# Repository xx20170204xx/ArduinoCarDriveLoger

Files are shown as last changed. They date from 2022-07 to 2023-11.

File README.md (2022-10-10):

# ArduinoCarDriveLoger
<!-- https://github.com/xx20170204xx/ArduinoCarDriveLoger -->

## description
Android+Arduino+Unityを使ってのマルチメーターを目指したものです。
※水温・油温・油圧計を表示できるようにしたもの

<!--
## Test
![TextMessage](UnityClient/MyMultiMeter/Assets/Image/icons.png)
-->

## Figure
### Android Client
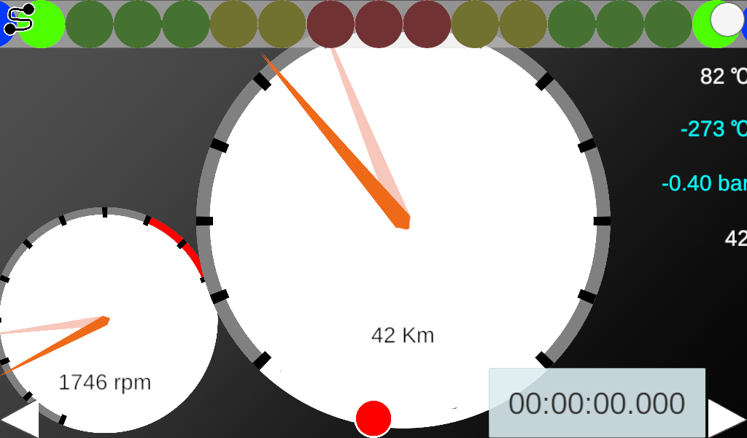
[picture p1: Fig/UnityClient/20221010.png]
Figure1. Client

### Device(Arduino Nano)
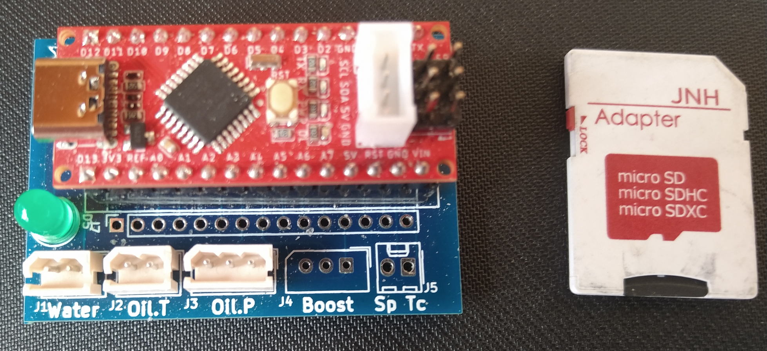
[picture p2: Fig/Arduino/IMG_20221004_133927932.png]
Figure2. Arduino Nano

### schematic
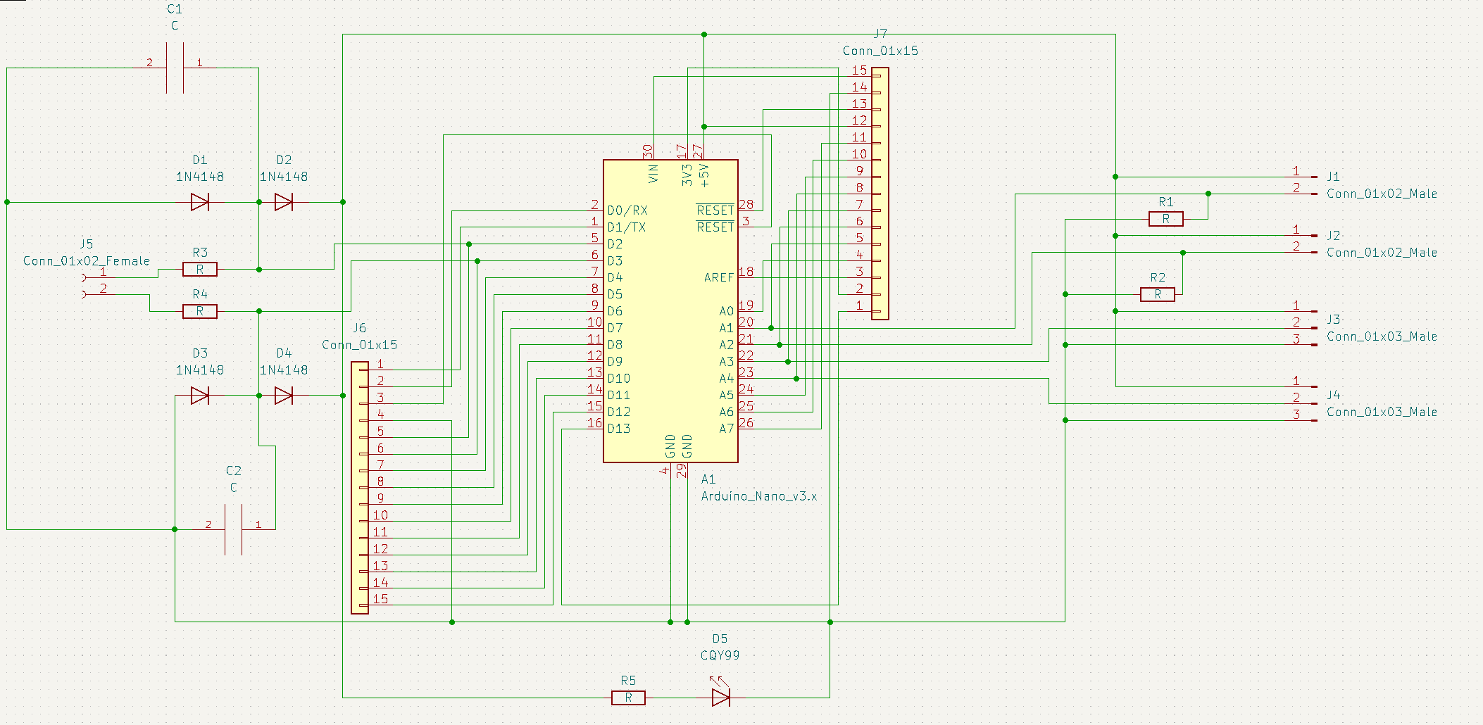
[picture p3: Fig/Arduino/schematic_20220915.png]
Figure3. Arduino Nano


2022/10/04
<!-- https://docs.github.com/ja/get-started/writing-on-github/getting-started-with-writing-and-formatting-on-github/basic-writing-and-formatting-syntax -->
<!-- EOF -->

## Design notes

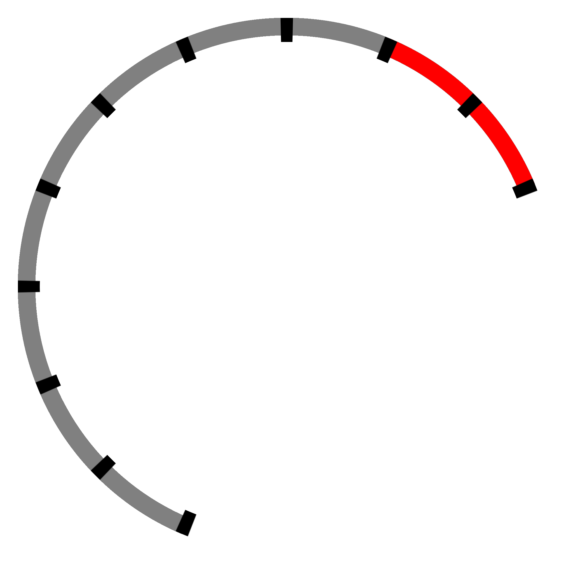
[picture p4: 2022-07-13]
UnityClient/MyMultiMeter/Assets/Image/TachoMeter.png

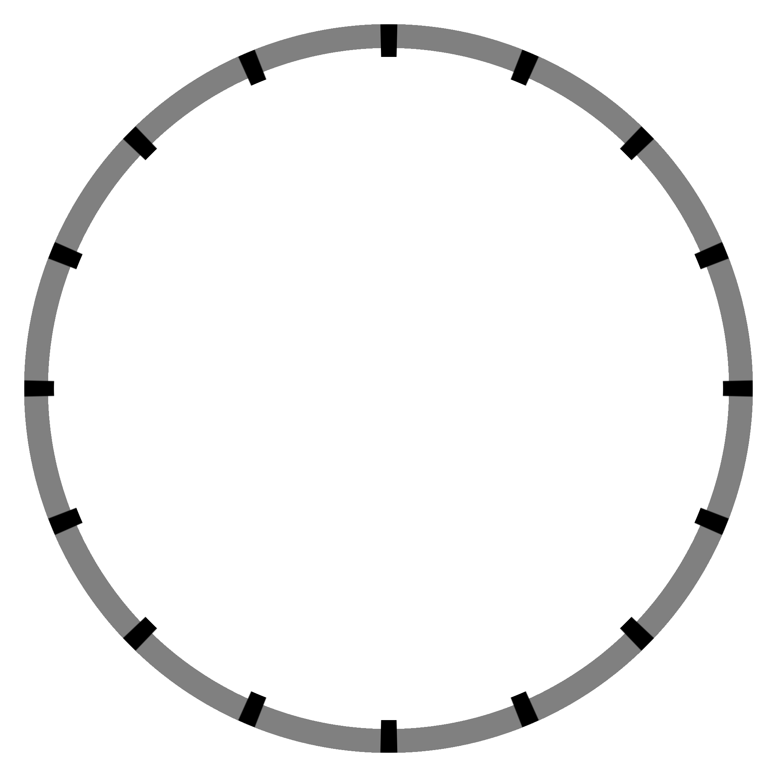
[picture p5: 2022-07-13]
UnityClient/MyMultiMeter/Assets/Image/MeterBase.png

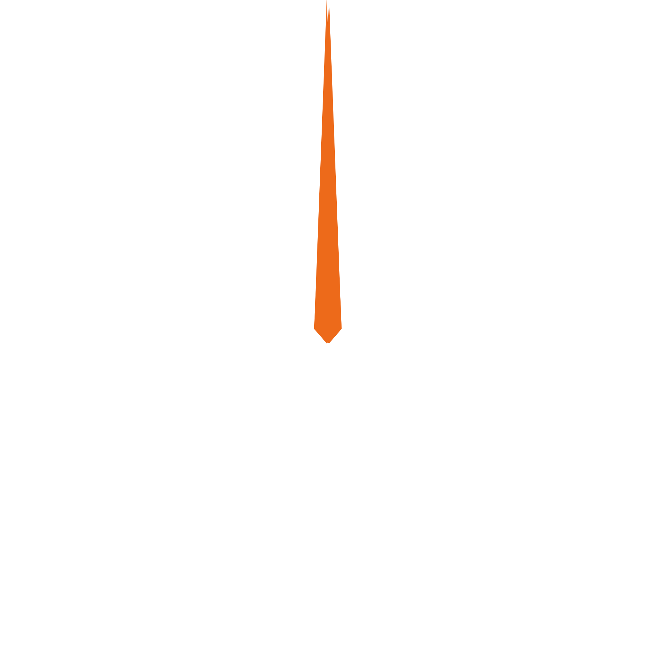
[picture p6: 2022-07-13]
UnityClient/MyMultiMeter/Assets/Image/MeterNeedle.png

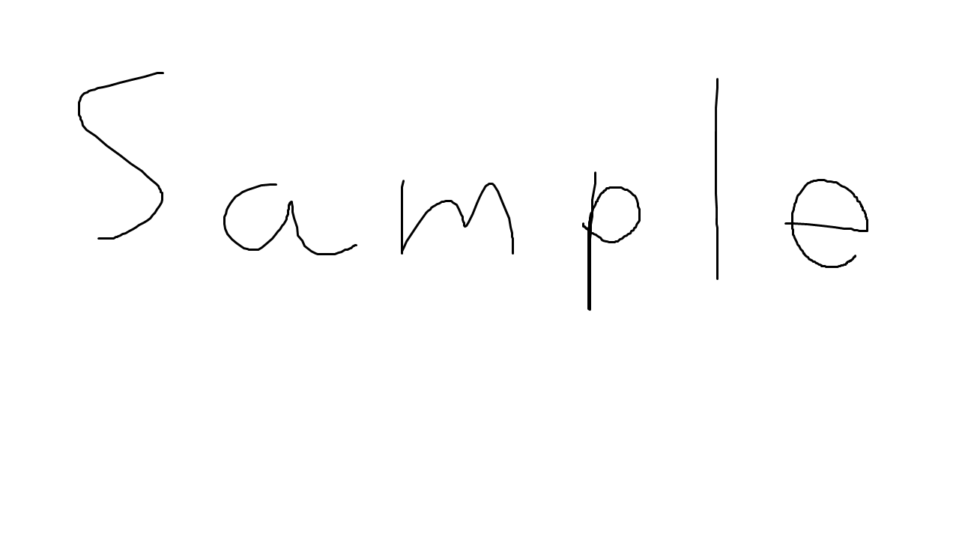
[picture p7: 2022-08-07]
UnityClient/MyMultiMeter/Assets/bundle/ModSample1/Thumbnail_Image.png

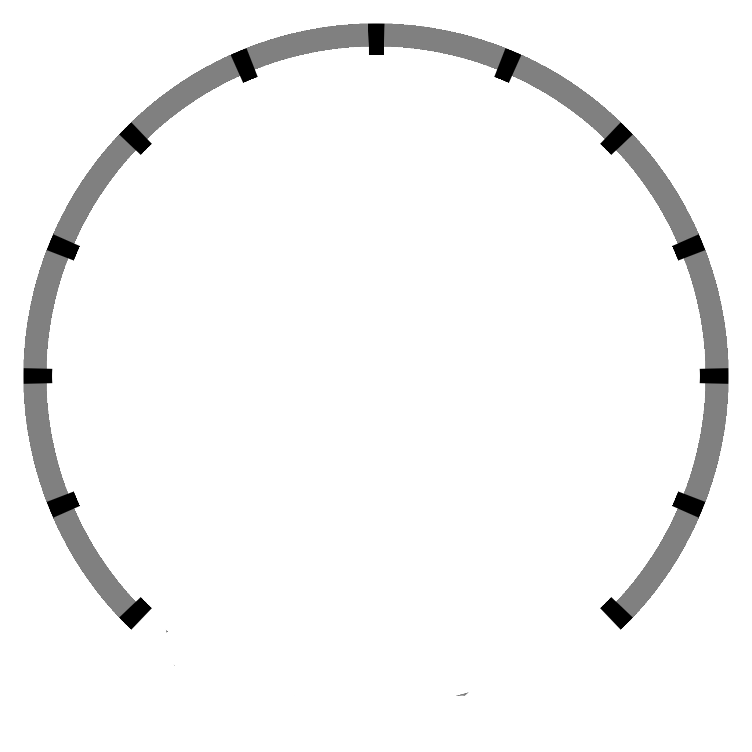
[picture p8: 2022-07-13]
UnityClient/MyMultiMeter/Assets/Image/SpeedMeter.png

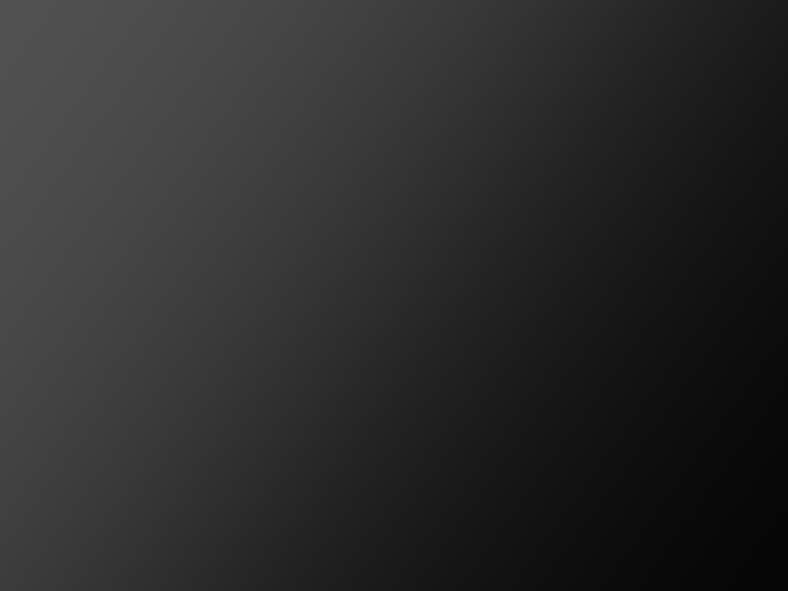
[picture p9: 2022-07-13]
UnityClient/MyMultiMeter/Assets/Image/background.png

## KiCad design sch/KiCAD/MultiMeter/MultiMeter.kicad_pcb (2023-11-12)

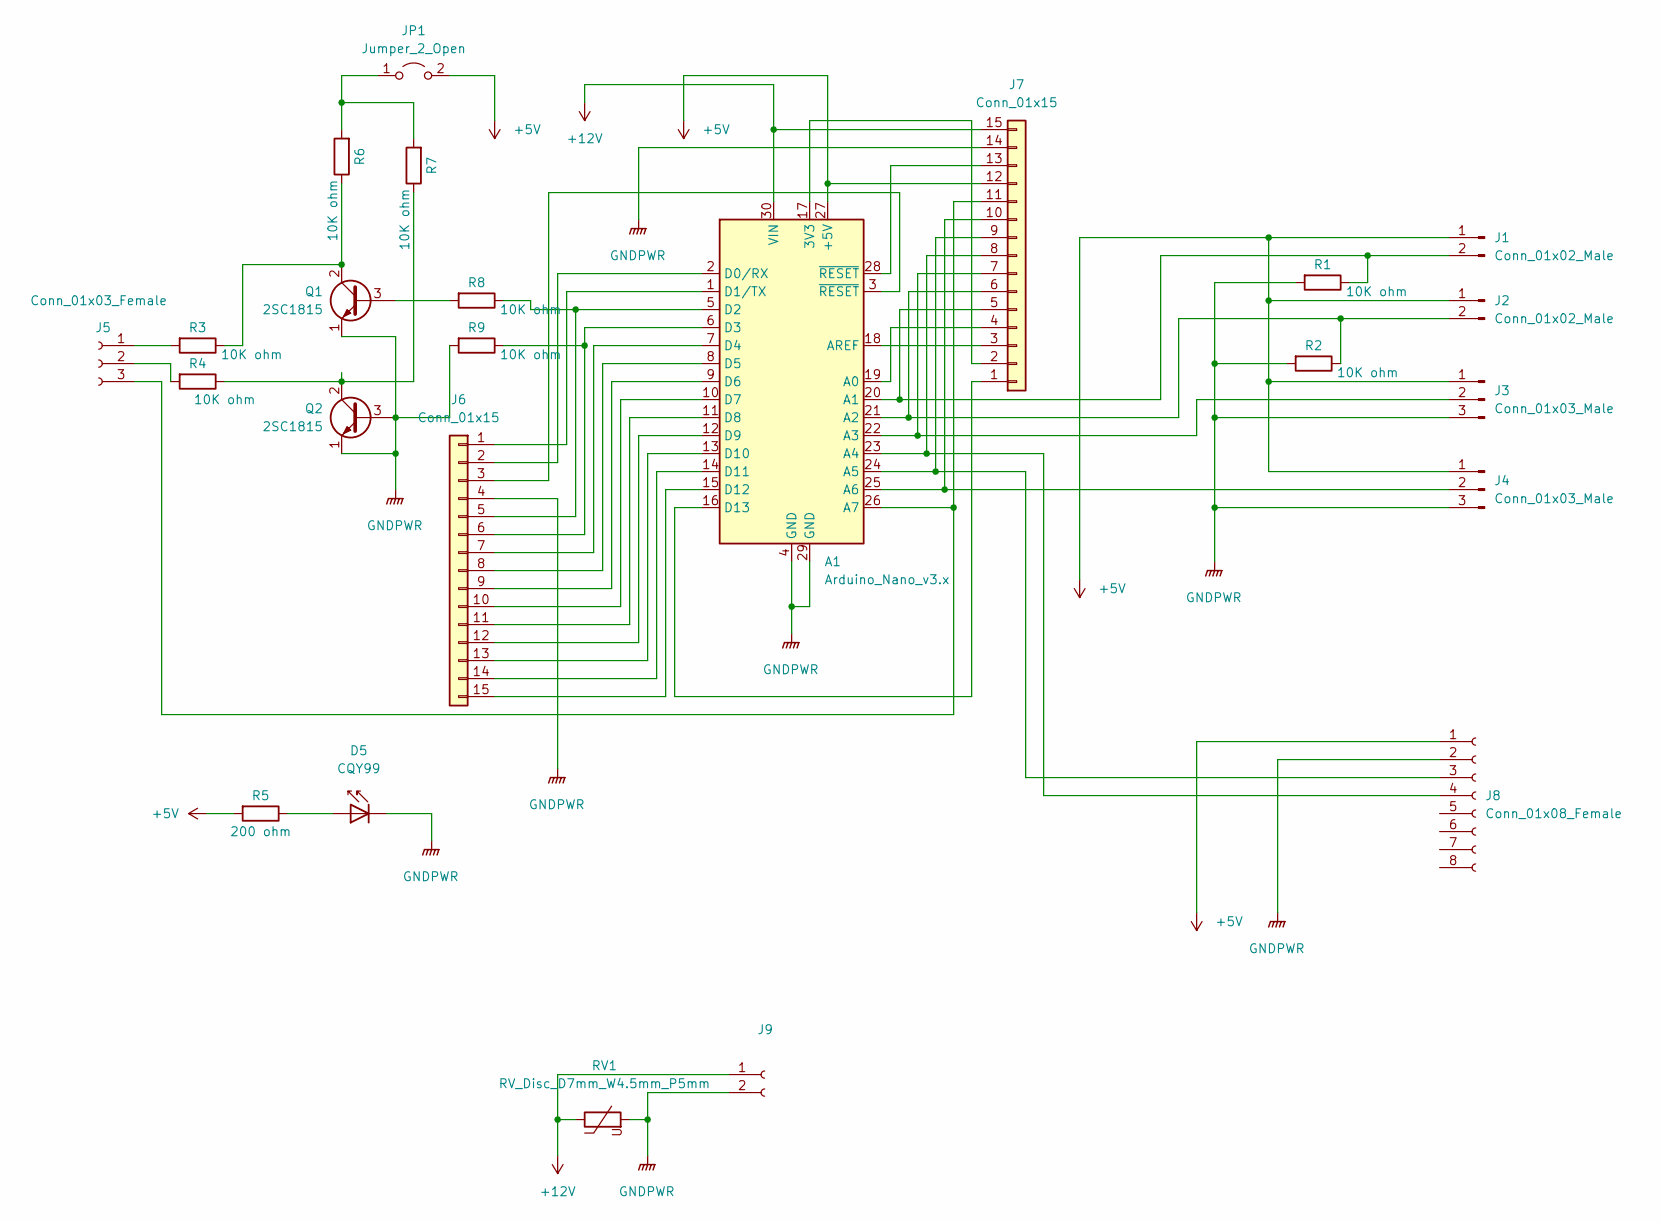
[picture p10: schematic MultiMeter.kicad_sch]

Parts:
A1: Arduino_Nano_v3.x; Arduino_Nano
D5: CQY99; LED_D5.0mm_IRGrey
J1, J2: Conn_01x02_Male; Molex_SPOX_5268-02A_1x02_P2.50mm_Horizontal
J3, J4: Conn_01x03_Male; Molex_SPOX_5268-03A_1x03_P2.50mm_Horizontal
J5: Conn_01x03_Female; Molex_KK-254_AE-6410-03A_1x03_P2.54mm_Vertical
J6, J7: Conn_01x15; PinSocket_1x15_P2.54mm_Vertical
J8: Conn_01x08_Female; JST_XH_B8B-XH-A_1x08_P2.50mm_Vertical
J9: (no value)
JP1: Jumper_2_Open; PinHeader_1x02_P2.54mm_Vertical
Q1, Q2: 2SC1815; TO-92_Inline
R1, R2, R3, R4, R6, R7, R8, R9: 10K ohm; R_Axial_DIN0204_L3.6mm_D1.6mm_P7.62mm_Horizontal
R5: 200 ohm; R_Axial_DIN0204_L3.6mm_D1.6mm_P7.62mm_Horizontal
RV1: RV_Disc_D7mm_W4.5mm_P5mm

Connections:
+5V: A1.27 (+5V), J1.1, J2.1, J3.1, J4.1, J7.12, J8.1, JP1.2 (B), R5.2
+12V: A1.30 (VIN), J7.15, J9.1, RV1.1
GNDPWR: A1.4 (GND), A1.29 (GND), D5.1 (K), J3.3, J4.3, J6.4, J7.14, J8.2, J9.2, Q1.1 (E), Q2.1 (E), Q2.3 (B), R1.2, R2.2, R9.2, RV1.2
unnamed: A1.1 (D1/TX), J6.1
unnamed: A1.2 (D0/RX), J6.2
unnamed: A1.3 (~RESET), J6.3
unnamed: A1.5 (D2), J6.5, R8.1
unnamed: A1.6 (D3), J6.6, R9.1
unnamed: A1.7 (D4), J6.7
unnamed: A1.8 (D5), J6.8
unnamed: A1.9 (D6), J6.9
unnamed: A1.10 (D7), J6.10
unnamed: A1.11 (D8), J6.11
unnamed: A1.12 (D9), J6.12
unnamed: A1.13 (D10), J6.13
unnamed: A1.14 (D11), J6.14
unnamed: A1.15 (D12), J6.15
unnamed: A1.16 (D13), J7.1
unnamed: A1.17 (3V3), J7.2
unnamed: A1.18 (AREF), J7.3
unnamed: A1.19 (A0), J7.4
unnamed: A1.20 (A1), J1.2, J7.5, R1.1
unnamed: A1.21 (A2), J2.2, J7.6, R2.1
unnamed: A1.22 (A3), J3.2, J7.7
unnamed: A1.23 (A4), J7.8, J8.4
unnamed: A1.24 (A5), J7.9, J8.3
unnamed: A1.25 (A6), J4.2, J7.10
unnamed: A1.26 (A7), J5.3, J7.11
unnamed: A1.28 (~RESET), J7.13
unnamed: D5.2 (A), R5.1
unnamed: J5.1, R3.2
unnamed: J5.2, R4.2
unnamed: JP1.1 (A), R6.2, R7.2
unnamed: Q1.2 (C), R3.1, R6.1
unnamed: Q1.3 (B), R8.2
unnamed: Q2.2 (C), R4.1, R7.1

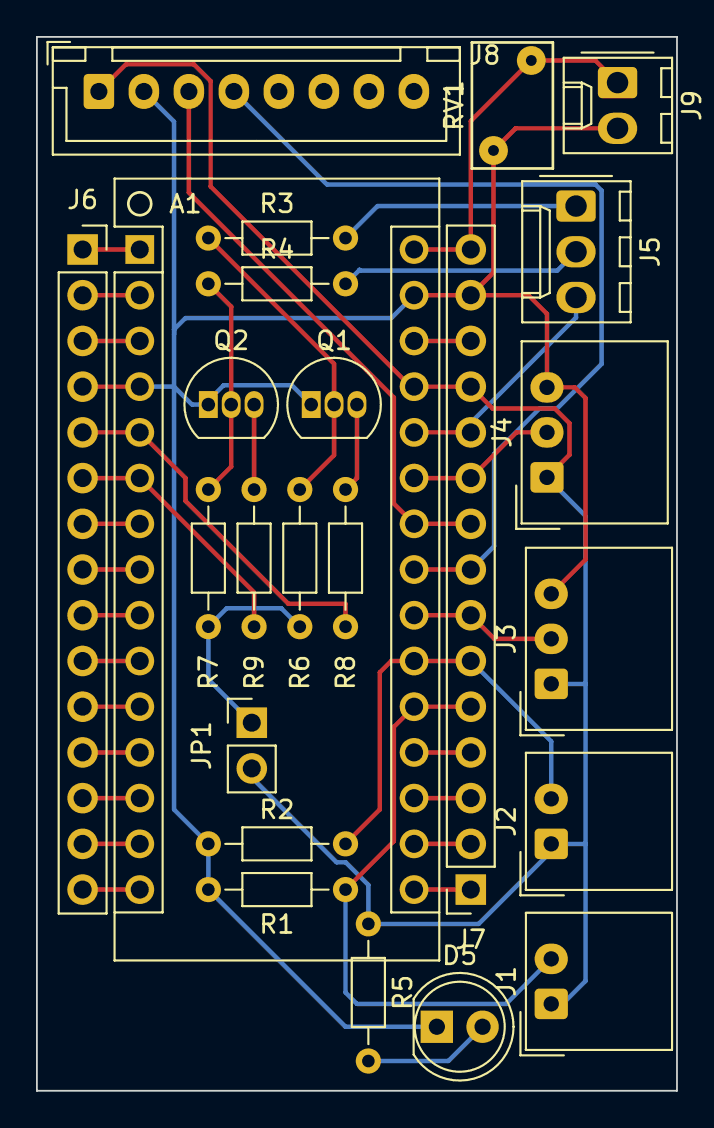
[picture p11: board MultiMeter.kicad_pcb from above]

Board: 2 copper layers, 35.6 x 58.5 mm, 24 parts (0 on the bottom side), 36 nets.

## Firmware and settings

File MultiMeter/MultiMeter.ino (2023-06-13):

/*
https://github.com/xx20170204xx/ArduinoCarDriveLoger/blob/main/MultiMeter/MultiMeter.ino

参考URL
https://github.com/puriso/arduino-thermometer_by_defi_sensor/blob/master/thermomerter_by_defi.ino/thermomerter_by_defi.ino.ino
https://github.com/matt-downs/arduino-oled-auto-gauges/blob/master/boost/boost.ino

[ Temp ]
[Sensor]
 |    |
 |    +--+
 |    |  |
 |    R  |
 |    |  |
+5V  GND A1
         A2

R= 1Kohm

[  Press ]
[ Sensor ]
 |   |  |
 |   |  |
 |   |  |
+5V GND A3

[  Boost ]
[ Sensor ]
 |   |  |
 |   |  |
 |   |  |
+5V GND A4

                       +-- ||---GND
                       |
+5V----------|<--------+---|<---GND
                       |
SpeedPulse---1Kohm-----+--------D2 or D3
    or
TachoPulse

diode : --|<--
        1N4148

*/

#define DEBUG_TACHOSPEED 0
#define DEBUG_TMP_PRS 0

const char* VERSION_STRING = "20221127XX";

#include <Wire.h>

const char SEP_CHAR= '\t';

/* 更新間隔(ms) */
const int UPDATE_DELAY = 100;

/* アナログピンの値を取得する際の回数 */
const int SENSOR_AVG_COUNT = 100;

/* 各センサーのアナログピン番号 */
const int WATER_SENSOR_PIN = 1;
const int OIL_SENSOR_PIN = 2;
const int PRESSURE_SENSOR_PIN = 3;
const int BOOST_SENSOR_PIN = 4;
/* 回転数取得用ピン(デジタル/割り込み可能) */
const int TACHO_PULSE_PIN = 2;
/* 車速取得用ピン(デジタル/割り込み可能) */
const int SPEED_PULSE_PIN = 3;

/*--------------------------------------*/
const int R25C   = 10000; // R25℃ = Ω
const int B      = 3380;  // B定数
const float K    = 273.16; // ケルビン
const float C25  = K + 25; // 摂氏25度

/* 1回転当たりの発生パルス数 */
/* 4, 8, 16, 20, 25 */
const int SPEED_PULSE_COUNT = 4;

const float SPEED_WARNING_VALUE = 61.0f;
const float RPM_WARNING_VALUE = 3000.0f;
const float SPEED_MAX = 400.0f;
const float RPM_MAX = 11000.0f;

/*--------------------------------------*/

/* 油温 */
float g_OilTmp = 0;
/* 油圧 */
float g_OilPrs = 0;
/* 水温 */
float g_WaterTmp = 0;
/* ブースト圧 */
float g_BoostPrs = 0;

volatile unsigned long g_tachoBefore = 0;//クランクセンサーの前回の反応時の時間
volatile unsigned long g_tachoAfter = 0;//クランクセンサーの今回の反応時の時間
volatile unsigned long g_tachoWidth = 0;//クランク一回転の時間　tachoAfter - tachoBefore
volatile float g_tachoRpm = 0;//エンジンの回転数[rpm]

volatile unsigned long g_speedBefore = 0;
volatile unsigned long g_speedAfter = 0;
volatile unsigned long g_speedWidth = 0;
volatile float g_speedKm = 0;//車速[Km/h]

// レジスタアドレス
#define MPU6050_ACCEL_XOUT_H 0x3B  // R  
#define MPU6050_WHO_AM_I     0x75  // R
#define MPU6050_PWR_MGMT_1   0x6B  // R/W
#define MPU6050_I2C_ADDRESS  0x68
// 構造体定義
typedef union accel_t_gyro_union {
  struct {
    uint8_t x_accel_h;
    uint8_t x_accel_l;
    uint8_t y_accel_h;
    uint8_t y_accel_l;
    uint8_t z_accel_h;
    uint8_t z_accel_l;
    uint8_t t_h;
    uint8_t t_l;
    uint8_t x_gyro_h;
    uint8_t x_gyro_l;
    uint8_t y_gyro_h;
    uint8_t y_gyro_l;
    uint8_t z_gyro_h;
    uint8_t z_gyro_l;
  } reg;
  struct {
    int16_t x_accel;
    int16_t y_accel;
    int16_t z_accel;
    int16_t temperature;
    int16_t x_gyro;
    int16_t y_gyro;
    int16_t z_gyro;
  } value;
};

typedef struct {
  float x;
  float y;
  float z;
} Vector3;

bool    g_mpu6050_init = false;
Vector3 g_acc;
Vector3 g_angle;
Vector3 g_gyro;
float   g_mpu6050_temp;

void setup() {
  static int error = 0;

  memset(&g_acc, 0, sizeof(g_acc) );
  memset(&g_angle, 0, sizeof(g_angle) );
  memset(&g_gyro, 0, sizeof(g_gyro) );
  g_mpu6050_temp = 0;

#if DEBUG_TACHOSPEED == 0
  /* Tacho */
  pinMode(TACHO_PULSE_PIN, INPUT_PULLUP);//ピンモードの設定
  attachInterrupt(digitalPinToInterrupt(TACHO_PULSE_PIN), InterruptTachoFunc, FALLING);//外部割り込み

  /* SPEED */
  pinMode(SPEED_PULSE_PIN, INPUT_PULLUP);//ピンモードの設定
  attachInterrupt(digitalPinToInterrupt(SPEED_PULSE_PIN), InterruptSpeedFunc, FALLING);//外部割り込み
#else
  /* nop */
#endif

  Wire.begin();
  Serial.begin(115200);
  error = InitMPU6050();
  if( error != 0 )
  {
    Serial.print("E\tReadMPU6050 Init error=");
    Serial.print(error);
    Serial.println("");
  }

  if( error == 0 )
  {
    g_mpu6050_init = true;
  }
}

void loop() {
  static int error = 0;
  if( g_mpu6050_init == true )
  {
    error = ReadMPU6050(&g_acc, &g_angle, &g_gyro, &g_mpu6050_temp);
    if( error != 0 )
    {
      Serial.print("E\tReadMPU6050 error=");
      Serial.print(error);
      Serial.println("");
    }
  }

  ReadSerialCommand();
#if DEBUG_TMP_PRS == 0
  UpdateSensorInfo();
#else
  UpdateDebugSensorInfo();
#endif
#if DEBUG_TACHOSPEED == 0
  UpdateTachoReset();
  UpdateSpeedReset();
#else
  UpdateDebugTachoSpeed();
#endif
  OutputSerial();
  delay(UPDATE_DELAY);
} /* loop */

static int InitMPU6050()
{
  int error;
  uint8_t cc;
  // 初回の読み出し
  error = MPU6050_read(MPU6050_WHO_AM_I, &cc, 1);
  if( error != 0 )
  {
    return error;
  }

  // 動作モードの読み出し
  error = MPU6050_read(MPU6050_PWR_MGMT_1, &cc, 1);
  if( error != 0 )
  {
    return error;
  }

  // MPU6050動作開始
  error = MPU6050_write_reg(MPU6050_PWR_MGMT_1, 0);

  return error;
} /* InitMPU6050 */

/*
pAcc    [ o]
pAngle  [ o]  Degree
pGyro   [ o]  Degree per second.
pTemp   [ o]  Degree
*/
static int ReadMPU6050(Vector3 *pAcc, Vector3 *pAngle, Vector3 *pGyro, float *pTemp)
{
  int error = 0;
  uint8_t swap;
  accel_t_gyro_union accel_t_gyro;
  accel_t_gyro_union *pData = &accel_t_gyro;

  error = MPU6050_read(MPU6050_ACCEL_XOUT_H, (uint8_t *)pData, sizeof(accel_t_gyro));
  if( error != 0 )
  {
    memset( pAcc, 0x00, sizeof(Vector3) );
    memset( pAngle, 0x00, sizeof(Vector3) );
    memset( pGyro, 0x00, sizeof(Vector3) );
    *pTemp = 0;
    return error;
  }
#define SWAP(x,y) swap = x; x = y; y = swap
  SWAP (pData->reg.x_accel_h, pData->reg.x_accel_l);
  SWAP (pData->reg.y_accel_h, pData->reg.y_accel_l);
  SWAP (pData->reg.z_accel_h, pData->reg.z_accel_l);
  SWAP (pData->reg.t_h,       pData->reg.t_l);
  SWAP (pData->reg.x_gyro_h,  pData->reg.x_gyro_l);
  SWAP (pData->reg.y_gyro_h,  pData->reg.y_gyro_l);
  SWAP (pData->reg.z_gyro_h,  pData->reg.z_gyro_l);
#undef SWAP

  // 取得した加速度値を分解能で割って加速度(G)に変換する
  pAcc->x = pData->value.x_accel / 16384.0;
  pAcc->y = pData->value.y_accel / 16384.0;
  pAcc->z = pData->value.z_accel / 16384.0;

  // 加速度からセンサ対地角を求める
  // Degree
  pAngle->x = atan2(pAcc->x, pAcc->z) * 360 / 2.0 / PI;
  pAngle->y = atan2(pAcc->y, pAcc->z) * 360 / 2.0 / PI;
  pAngle->z = atan2(pAcc->x, pAcc->y) * 360 / 2.0 / PI;

  // 取得した角速度値を分解能で割って角速度(degrees per sec)に変換する
  pGyro->x = pData->value.x_gyro / 131.0;
  pGyro->y = pData->value.y_gyro / 131.0;
  pGyro->z = pData->value.z_gyro / 131.0;

  *pTemp = ( (float) accel_t_gyro.value.temperature + 12412.0f) / 340.0f;

  return error;
} /* ReadMPU6050 */


static void ReadSerialCommand()
{
  char cmd = Serial.read();
  switch(cmd)
  {
    /* Version */
    case 'V':
      {
        Serial.print('V');
        Serial.print(SEP_CHAR);
        Serial.println(VERSION_STRING);
      }
      break;
  }
} /* ReadSerialCommand */

static void OutputSerial( void ){
  char bufVars[0x10][10+1];
  memset( bufVars, 0x00, sizeof(bufVars) );

  // 浮動小数点を文字列に変換
  dtostrf(g_WaterTmp,    3,4, bufVars[0] );
  dtostrf(g_OilTmp,      3,4, bufVars[1] );
  dtostrf(g_OilPrs,      3,4, bufVars[2] );
  dtostrf(g_BoostPrs,    3,4, bufVars[3] );
  dtostrf(g_tachoRpm,    5,0, bufVars[4] );
  dtostrf(g_speedKm,     3,0, bufVars[5] );

  dtostrf(g_mpu6050_temp,3,5, bufVars[6] );
  dtostrf(g_acc.x,       2,5, bufVars[7] );
  dtostrf(g_acc.y,       2,5, bufVars[8] );
  dtostrf(g_acc.z,       2,5, bufVars[9] );
  dtostrf(g_angle.x,     4,5, bufVars[10] );
  dtostrf(g_angle.y,     4,5, bufVars[11] );
  dtostrf(g_angle.z,     4,5, bufVars[12] );
  // dtostrf(g_gyro.x,      4,5, bufVars[13] );
  // dtostrf(g_gyro.y,      4,5, bufVars[14] );
  // dtostrf(g_gyro.z,      4,5, bufVars[15] );

  /* A = 10 */
  /* C = 12 */
  /* D = 13 */
  /* F = 15 */
  /* G = 16 */
  Serial.print("DD");
  Serial.print(SEP_CHAR);
  for( int ii = 0; ii < 0x0D; ii++ )
  {
    Serial.print(bufVars[ii]);
    Serial.print(SEP_CHAR);
  }
  Serial.println("");

} /* OutputSerial */

static void UpdateSensorInfo()
{
  float wtr_avg = 0;
  float oilT_avg = 0;
  float oilP_avg = 0;

  // センサーから各温度・圧力を取得
  g_WaterTmp  = get_temp(WATER_SENSOR_PIN);
  g_OilTmp    = get_temp(OIL_SENSOR_PIN);
  g_OilPrs  = get_oil_pressure(PRESSURE_SENSOR_PIN);
  g_BoostPrs  = get_boost_press(BOOST_SENSOR_PIN);

} /* UpdateSensorInfo */

// 油圧取得(bar)
static float get_oil_pressure( int pinNum ){
  double input_for_value = analogReadAvg(pinNum, SENSOR_AVG_COUNT);

  float vo = (float)input_for_value * 5.0f / 1023.0f;
  float ret = 250 * (vo - 0.480) * 0.0101972;

  return ret;
} /* get_oil_pressure */

// 温度取得(摂氏)
static float get_temp( const int pinNum ){
  float out_tmp;
  float res;

  double input_for_value = analogReadAvg(pinNum, SENSOR_AVG_COUNT);

  res = resistance_by_input((int)input_for_value);
  out_tmp = convert_temp_by_ntc(res);
 
  return out_tmp;
} /* get_temp */

// 入力から抵抗値を求める(5V)
static float resistance_by_input(int input) {
  float vout = input / 1023.0f * 5.0f; //分圧した出力電圧の計算
  float r = ((5.0 / vout) - 1.0f) * R25C; //サーミスタ抵抗計算
  return r;
} /* resistance_by_input */

// NTCサーミスタでの温度
static float convert_temp_by_ntc(float r) {
  return B / (log(r/R25C) + (B/C25)) - K;
} /* convert_temp_by_ntc */

/* ブースト圧(kPa) */
static float get_boost_press( const int pinNum )
{
  float ret_psi;
  float ret_kpa;
  double input_for_value = analogReadAvg(pinNum, SENSOR_AVG_COUNT);
  ret_psi=(((input_for_value - 102) / 0.1798f ) - 1535) * 0.01f;
  ret_kpa = ret_psi * 6.895f;
  return ret_kpa;
} /* get_boost_press */

static void InterruptTachoFunc( void )
{
//const float SPEED_MAX = 400.0f;
//const float RPM_MAX = 11000.0f;
  const float ONE_MIN_USEC = 60.0f * 1000.0f * 1000.0f;
  float _tachoRpm = 0;

  g_tachoAfter = micros();//現在の時刻を記録
  g_tachoWidth = g_tachoAfter - g_tachoBefore;//前回と今回の時間の差を計算
  g_tachoBefore = g_tachoAfter;//今回の値を前回の値に代入する
  if( g_tachoWidth <= 0 )
  {
    return;
  }
  _tachoRpm = ONE_MIN_USEC / (g_tachoWidth * 2.0f);//タイヤの回転数[rpm]を計算

  /* 回転数の最大値を超えていた場合、誤検知とする */
  if( _tachoRpm >= RPM_MAX )
  {
    return;
  }

  g_tachoRpm = _tachoRpm;
} /* InterruptTachoFunc */

static void InterruptSpeedFunc( void )
{
  const float CSPD = 60.0 * 60 / (637 * SPEED_PULSE_COUNT) * 1000 * 1000;
  float _speedKm = 0;

  g_speedAfter = micros();//現在の時刻を記録
  g_speedWidth = g_speedAfter - g_speedBefore;//前回と今回の時間の差を計算
  g_speedBefore = g_speedAfter;//今回の値を前回の値に代入する
  if( g_speedWidth <= 0 )
  {
    return;
  }
  _speedKm = CSPD / g_speedWidth;
  /* 速度の最大値を超えていた場合、誤検知とする */
  if( _speedKm >= SPEED_MAX )
  {
    return;
  }
  
  /* 加速度が10を超えていた場合、誤検知とする */
  if( fabs(g_speedKm - _speedKm) > 10 )
  {
    return;
  }

  g_speedKm = _speedKm;
} /* InterruptSpeedFunc */

/*
  パルスが入らない状態を確認して 0rpmを設定する
*/
static void UpdateTachoReset( void ){
  const float ONE_MIN_USEC = 60.0f * 1000.0f * 1000.0f / 2.0f;
  const float CSPD = 60.0 * 60 / (637 * SPEED_PULSE_COUNT) * 1000 * 1000;
  unsigned long width = micros() - g_tachoBefore;
  if( width <= CSPD )
    return;

  if( width <= 0 )
  {
    g_tachoWidth = 0.0f;
    g_tachoBefore = micros();
    g_tachoAfter = g_tachoBefore;
    return;
  }

  g_tachoWidth = 0.0f;
  g_tachoRpm = 0.0f;

} /* UpdateTachoReset */

/*
  パルスが入らない状態を確認して 0Kmを設定する
*/
static void UpdateSpeedReset( void ){
  const float CSPD = 60.0 * 60 / (637 * SPEED_PULSE_COUNT) * 1000 * 1000;
  unsigned long width = micros() - g_speedBefore;
  if( width <= CSPD )
    return;

  if( width <= 0 )
  {
    g_speedWidth = 0.0f;
    g_speedBefore = micros();
    g_speedAfter = g_speedBefore;
    return;
  }
  g_speedWidth = 0.0f;
  g_speedKm = 0.0f;

} /* UpdateSpeedReset */

// 指定したアナログピンを指定回数取得した平均を返す
static double analogReadAvg( int pinNum , int count )
{
  double input_for_value = 0;
  for( int ii = 0; ii < count; ii++ ) { input_for_value += analogRead(pinNum); }
  input_for_value /= count;
  return input_for_value;
} /* analogReadAvg */


static void UpdateDebugTachoSpeed( void ){
#define RPM_MAX   8000
#define SPEED_MAX  300
    static int GEAR = 0;
    static float GEARS[] = { 
        0.0f,     // N
        183.068f, // 1st
        106.008f, // 2nd
        71.938f,  // 3rd
        52.716f,  // 4th
        43.163f   // 5th
    };
    g_tachoRpm += RPM_MAX * 0.1f * ( 100.0f / 1000.0f );
    g_tachoWidth = 1;

    g_speedKm = (GEARS[GEAR] != 0.0f ? g_tachoRpm / GEARS[GEAR] : 0.0f);
    
    if( g_tachoRpm  >= RPM_MAX )
    {
      g_tachoRpm = 750.0f;
      GEAR += 1;
    }
    if( GEAR > 5 )
    {
      GEAR = 0;
    }


} /* UpdateDebugTachoSpeed */

static void UpdateDebugSensorInfo( void )
{
/*
float g_OilTmp = 0;    // 油温
float g_OilPrs = 0;    // 油圧
float g_WaterTmp = 0;  // 水温
float g_BoostPrs = 0;  // ブースト圧
*/
    static float TMP_MIN = -20.0f;
    static float TMP_MAX = 150.0f;

    /* bar */
    static float PRS_MIN = -1.5f;
    static float PRS_MAX = 12.0f;

    g_OilTmp += TMP_MAX * 0.1f * ( 100.0f / 1000.0f );
    g_WaterTmp += TMP_MAX * 0.1f * ( 100.0f / 1000.0f );

    g_OilPrs += PRS_MAX * 0.1f * ( 100.0f / 1000.0f );



    if( g_OilTmp >= TMP_MAX ){ g_OilTmp = TMP_MIN; }
    if( g_WaterTmp >= TMP_MAX ){ g_WaterTmp = TMP_MIN; }

    if( g_OilPrs >= PRS_MAX ){ g_OilPrs = PRS_MIN; }


} /* UpdateDebugSensorInfo */

// MPU6050_read
int MPU6050_read(int start, uint8_t *buffer, int size) {
  int ii, nn, error;
  Wire.beginTransmission(MPU6050_I2C_ADDRESS);
  nn = Wire.write(start);
  if (nn != 1) {
    return (-10);
  }
  nn = Wire.endTransmission(false);// hold the I2C-bus
  if (nn != 0) {
    return (nn);
  }
  // Third parameter is true: relase I2C-bus after data is read.
  Wire.requestFrom(MPU6050_I2C_ADDRESS, size, true);
  ii = 0;
  while (Wire.available() && ii < size) {
    buffer[ii++] = Wire.read();
  }
  if ( ii != size) {
    return (-11);
  }
  return (0); // return : no error
} /* MPU6050_read */

// MPU6050_write
int MPU6050_write(int start, const uint8_t *pData, int size) {
  int nn, error;
  Wire.beginTransmission(MPU6050_I2C_ADDRESS);
  nn = Wire.write(start);// write the start address
  if (nn != 1) {
    return (-20);
  }
  nn = Wire.write(pData, size);// write data bytes
  if (nn != size) {
    return (-21);
  }
  error = Wire.endTransmission(true); // release the I2C-bus
  if (error != 0) {
    return (error);
  }

  return (0);// return : no error
} /* MPU6050_write */

// MPU6050_write_reg
int MPU6050_write_reg(int reg, uint8_t data) {
  int error;
  error = MPU6050_write(reg, &data, 1);
  return (error);
} /* MPU6050_write_reg */

/* EOF */

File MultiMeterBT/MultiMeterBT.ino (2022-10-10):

/*
https://github.com/xx20170204xx/ArduinoCarDriveLoger/blob/main/MultiMeterBT/MultiMeterBT.ino

参考URL
https://github.com/puriso/arduino-thermometer_by_defi_sensor/blob/master/thermomerter_by_defi.ino/thermomerter_by_defi.ino.ino
https://github.com/matt-downs/arduino-oled-auto-gauges/blob/master/boost/boost.ino

[ Temp ]
[Sensor]
 |    |
 |    +--+
 |    |  |
 |    R  |
 |    |  |
+5V  GND A1
         A2

R= 1Kohm

[  Press ]
[ Sensor ]
 |   |  |
 |   |  |
 |   |  |
+5V GND A3

[  Boost ]
[ Sensor ]
 |   |  |
 |   |  |
 |   |  |
+5V GND A4

                       +-- ||---GND
                       |
+5V----------|<--------+---|<---GND
                       |
SpeedPulse---1Kohm-----+--------D2 or D3
    or
TachoPulse

diode : --|<--
        1N4148

*/

#define DEBUG_TACHOSPEED 1
#define DEBUG_TMP_PRS 1
#define USE_LCD 0

const char* VERSION_STRING = "20220716XX";

#include "BluetoothSerial.h"
#if !defined(CONFIG_BT_ENABLED) || !defined(CONFIG_BLUEDROID_ENABLED)
#error Bluetooth is not enabled! Please run `make menuconfig` to and enable it
#endif

#if !defined(CONFIG_BT_SPP_ENABLED)
#error Serial Bluetooth not available or not enabled. It is only available for the ESP32 chip.
#endif

BluetoothSerial SerialBT;
boolean confirmRequestPending = true;

#if USE_LCD == 1
// include the library code:
#include <LiquidCrystal.h>

/* LCD操作ボタン */
enum LCD_BUTTONS {
  LCD_BUTTON_NONE,
  LCD_BUTTON_UP,
  LCD_BUTTON_DOWN,
  LCD_BUTTON_LEFT,
  LCD_BUTTON_RIGHT,
  LCD_BUTTON_SELECT  
};
#endif

/* LCD Button 各抵抗値 */
const int LCD_BUTTON_VAR_NONE=1024;
const int LCD_BUTTON_VAR_SELECT=721;
const int LCD_BUTTON_VAR_LEFT=479;
const int LCD_BUTTON_VAR_DOWN=308;
const int LCD_BUTTON_VAR_UP=132;
const int LCD_BUTTON_VAR_RIGHT=0;

const char SEP_CHAR= '\t';

/* 更新間隔(ms) */
const int UPDATE_DELAY = 100;

/* アナログピンの値を取得する際の回数 */
const int SENSOR_AVG_COUNT = 100;

/* 各センサーのアナログピン番号 */
const int WATER_SENSOR_PIN = 1;
const int OIL_SENSOR_PIN = 2;
const int PRESSURE_SENSOR_PIN = 3;
const int BOOST_SENSOR_PIN = 4;
/* 回転数取得用ピン(デジタル/割り込み可能) */
const int TACHO_PULSE_PIN = 2;
/* 車速取得用ピン(デジタル/割り込み可能) */
const int SPEED_PULSE_PIN = 3;
/* 設定速度超過用ピン */
const int SPEED_WARNING_PIN=10;
/* 設定回転数超過用ピン */
const int RPM_WARNING_PIN=11;

/*--------------------------------------*/
const int R25C   = 10000; // R25℃ = Ω
const int B      = 3380;  // B定数
const float K    = 273.16; // ケルビン
const float C25  = K + 25; // 摂氏25度

/* 1回転当たりの発生パルス数 */
/* 4, 8, 16, 20, 25 */
const int SPEED_PULSE_COUNT = 4;

const float SPEED_WARNING_VALUE = 61.0f;
const float RPM_WARNING_VALUE = 3000.0f;

/*--------------------------------------*/

/* 油温 */
float g_OilTmp = 0;
/* 油圧 */
float g_OilPrs = 0;
/* 水温 */
float g_WaterTmp = 0;
/* ブースト圧 */
float g_BoostPrs = 0;

volatile unsigned long g_tachoBefore = 0;//クランクセンサーの前回の反応時の時間
volatile unsigned long g_tachoAfter = 0;//クランクセンサーの今回の反応時の時間
volatile unsigned long g_tachoWidth = 0;//クランク一回転の時間　tachoAfter - tachoBefore
volatile float g_tachoRpm = 0;//エンジンの回転数[rpm]

volatile unsigned long g_speedBefore = 0;
volatile unsigned long g_speedAfter = 0;
volatile unsigned long g_speedWidth = 0;
volatile float g_speedKm = 0;//車速[Km/h]


#if USE_LCD == 1
// initialize the library by associating any needed LCD interface pin
// with the arduino pin number it is connected to
const int rs = 8, en = 9, d4 = 4, d5 = 5, d6 = 6, d7 = 7;
LiquidCrystal lcd(rs, en, d4, d5, d6, d7);
/* 表示モード */
int g_LCDmode=0;
#endif

void BTConfirmRequestCallback(uint32_t numVal)
{
  Serial.println(numVal);
  confirmRequestPending = true;
} /* BTConfirmRequestCallback */

void BTAuthCompleteCallback(boolean success)
{
  confirmRequestPending = false;
  if (success)
  {
    Serial.println("Pairing success!!");
  }
  else
  {
    Serial.println("Pairing failed, rejected by user!!");
  }
} /* BTAuthCompleteCallback */

void BTconfirmRequest(void)
{
  Serial.println("BTconfirmRequest.");
  SerialBT.confirmReply(true);
} /* BTconfirmRequest */

void setup() {

  // 20220802 : PIN番号が使用できないためコメントアウト
  // pinMode(SPEED_WARNING_PIN, OUTPUT);
  // pinMode(RPM_WARNING_PIN, OUTPUT);

#if DEBUG_TACHOSPEED == 0
  /* Tacho */
  pinMode(TACHO_PULSE_PIN, INPUT_PULLUP);//ピンモードの設定
  attachInterrupt(digitalPinToInterrupt(TACHO_PULSE_PIN), InterruptTachoFunc, FALLING);//外部割り込み

  /* SPEED */
  pinMode(SPEED_PULSE_PIN, INPUT_PULLUP);//ピンモードの設定
  attachInterrupt(digitalPinToInterrupt(SPEED_PULSE_PIN), InterruptSpeedFunc, FALLING);//外部割り込み
#else
  /* nop */
#endif

  Serial.begin(115200);
  Serial.println("setup.");
  // SerialBT.enableSSP();
  // SerialBT.onConfirmRequest(BTConfirmRequestCallback);
  // SerialBT.onAuthComplete(BTAuthCompleteCallback);
  SerialBT.begin("MMM_BT"); //Bluetooth device name
  // Serial.println("The device started, now you can pair it with bluetooth!");
  confirmRequestPending = false;

#if USE_LCD == 1
  // set up the LCD's number of columns and rows:
  lcd.begin(16, 2);
  lcd.clear();
#endif
}

void loop() {
  if (confirmRequestPending == true)
  {
    BTconfirmRequest();
    delay(UPDATE_DELAY);
    return;
  }
  ReadSerialCommand();
#if DEBUG_TMP_PRS == 0
  UpdateSensorInfo();
#else
  UpdateDebugSensorInfo();
#endif
#if DEBUG_TACHOSPEED == 0
  UpdateTachoReset();
  UpdateSpeedReset();
#else
  UpdateDebugTachoSpeed();
#endif
  OutputSerial();
  OutputWarningPin();
#if USE_LCD == 1
  UpdateLCD();
#endif
  delay(UPDATE_DELAY);
} /* loop */

static void ReadSerialCommand()
{
  char cmd = SerialBT.read();
  switch(cmd)
  {
    /* Version */
    case 'V':
      {
        SerialBT.print('V');
        SerialBT.print(SEP_CHAR);
        SerialBT.println(VERSION_STRING);
      }
      break;
  }
} /* ReadSerialCommand */

static void OutputSerial( void ){
  char bufVars[6][10+1];
  char bufOut[256];
  memset( bufVars, 0x00, sizeof(bufVars) );
  memset( bufOut, 0x00, sizeof(bufOut) );

  // 浮動小数点を文字列に変換
  dtostrf(g_WaterTmp,    3,4, bufVars[0] );
  dtostrf(g_OilTmp,      3,4, bufVars[1] );
  dtostrf(g_OilPrs,      3,4, bufVars[2] );
  dtostrf(g_tachoRpm,    5,0, bufVars[3] );
  dtostrf(g_speedKm,     3,0, bufVars[4] );
  // dtostrf(g_BoostPrs,    3,4, bufVars[5] );

/*
  SerialBT.print('D');
  SerialBT.print(SEP_CHAR);
  for( int ii = 0; ii < 5; ii++ )
  {
    SerialBT.print(bufVars[ii]);
    SerialBT.print(SEP_CHAR);
  }*/
  sprintf( bufOut, "D%c%s%c%s%c%s%c%s%c%s", SEP_CHAR,
    bufVars[0],SEP_CHAR,
    bufVars[1],SEP_CHAR,
    bufVars[2],SEP_CHAR,
    bufVars[3],SEP_CHAR,
    bufVars[4]
    );
  SerialBT.println(bufOut);

} /* OutputSerial */

static void UpdateSensorInfo()
{
  float wtr_avg = 0;
  float oilT_avg = 0;
  float oilP_avg = 0;

  // センサーから各温度・圧力を取得
  g_WaterTmp = get_temp(WATER_SENSOR_PIN);
  g_OilTmp = get_temp(OIL_SENSOR_PIN);
  g_OilPrs = get_oil_pressure(PRESSURE_SENSOR_PIN);
  // g_BoostPrs = get_boost_press(BOOST_SENSOR_PIN);

} /* UpdateSensorInfo */
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

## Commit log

2022-05-19 Defiのセンサーから情報を取得するプログラムを追加
2022-05-19 [未テスト]回転数/スピード取得機能追加
2022-06-12 ・LCDの表示を修正 ・一定時間車速パルスが入らない場合、速度を0Km/hに設定する ・シリアル出力に回転数/速度を追加
2022-06-15 ・デバック用にダミーの回転数、速度を出力できるようにした。 ・回転数をリセットする機能を追加
2022-06-19 警告用のピンを追加
2022-06-19 シリアル通信にて外部からのコマンドを受け付けるように修正
2022-07-13 クライアント用のプログラムを追加(Unity)
2022-07-13 SerialPortUtilityProを使用するように修正
2022-07-13 Opningの構成を修正
2022-07-13 関数の構成を修正
2022-07-13 gitclone追加
2022-07-13 単位の間違いを修正 Kpa -> bar
    [MultiMeter.ino]
2022-07-13 シーンの切り替えの指定方法を修正 名前 -> インデックス 不要なメンバ関数を削除
2022-07-15 デバイスリスト表示用パネルを追加
2022-07-15 ブースト圧用関数を追加
2022-07-15 センサーの値を取得する際、指定した回数取得した平均値をを取得するように修正
2022-07-15 prefabから不要なスクリプトを削除
2022-07-15 シリアル通信で使用するデータ項目を修正（平均値を削除）
2022-07-16 接続するデバイスの情報を保存するように修正
2022-07-16 バグ修正
2022-07-16 CSV出力できるように修正
2022-07-17 ・水温/油温/油圧の値をデバック用の値を出力できるように修正
2022-07-23 ・LampMeterを追加 ・GPS位置情報を取得できるように修正 ・サブメーター設定を追加(同じ値を別の表現で表示できる)
2022-07-24 アイコンの追加
2022-08-01 ・opningの背景修正 ・TachoShiftLampMeterの点灯条件を修正 ・減速比表示を正式に追加 ・(バグ要修正)画面サイズによってDeviceListが選択できない
2022-08-02 Skip機能を追加
2022-08-02 ・デバック出力を追加 ・接続出来るデバイスがUSBのみだったのを修正 ・シリアルの速度を修正(115200bps)
2022-08-02 Bluetooth用のinoを追加
2022-08-02 Bluetooth用を作成する際にバグになった部分をコメントアウト
2022-08-02 README.mdにFigureを追加
2022-08-02 画像のサイズを変更
2022-08-02 README.mdを修正
2022-08-06 ・DeviceListの表示バグを修正 ・デバイス情報の表示を簡略化
2022-08-06 companyNameを修正
2022-08-06 ・RecordButtonの表示を修正
2022-08-06 関数名変更Dev -> DevInfo
2022-08-07 MODに対応中
2022-08-07 メモ追加
2022-08-07 文字コード修正 メーターの動作修正
2022-08-14 ストップウォッチの機能を追加
2022-08-17 メーターの表示を調整
2022-08-17 Google Mapを表示できるように修正中
2022-08-17 説明などを修正
2022-08-17 KiCADで制作した物を追加
    [MultiMeter-B_Cu.gbr, MultiMeter-B_Mask.gbr, MultiMeter-B_Paste.gbr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]
2022-08-17 回路図の間違いを修正
    [MultiMeter.kicad_sch]
2022-09-12 回路図データ修正
    [MultiMeter-B_Cu.gbr, MultiMeter-B_Mask.gbr, MultiMeter-B_Paste.gbr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]
2022-09-13 デバック用PADを追加
    [MultiMeter.kicad_pcb, MultiMeter.kicad_sch]
2022-09-15 確認用LEDを追加
    [MultiMeter-B_Cu.gbr, MultiMeter-B_Mask.gbr, MultiMeter-B_Paste.gbr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]
2022-09-24 メーターの各種設定を変えられるように修正中
2022-09-24 Inspectorから実行できるデモモードを追加
2022-09-24 normalColorを廃止
2022-09-24 回路図微修正
    [MultiMeter.kicad_pcb, MultiMeter.kicad_sch]
2022-09-25 Voiceを出力するように修正中
2022-09-28 ・記録状態の切り替え時にSEを出力 ・ボイスを入れ替え
    [VoiceList.xlsx]
2022-09-28 SEを修正
    [VoiceList.xlsx]
2022-09-29 サウンドチェック用ツールを追加
2022-10-06 ・Mixer追加 ・音声追加 ・メーターの表示修正
    [VoiceList.xlsx]
2022-10-09 SEの再生条件を修正
2022-10-09 インデントを修正
2022-10-09 パネルの順番を修正
2022-10-09 初期表示でメーターの設定を取得するように修正
2022-10-10 条件修正
    [VoiceList.xlsx]
2022-10-10 文字コード修正
2022-10-10 SEを鳴らすように修正
    [VoiceList.xlsx]
2022-10-10 回転数リセットのタイミングを修正
2022-10-10 アイコンを追加
2022-10-12 回転数、速度が明らかに異常な値になるのを修正中
2022-10-12 関数の定義位置を修正
2022-10-13 ブースト圧を取得できるように修正中
2022-10-13 ブースト圧を表示できるように修正中
2022-10-13 Boostの算出方法を修正
2022-10-13 Boost周りの表示および値の範囲を修正
2022-10-13 Boostの資料を追加
    [Boost.xlsx]
2022-10-14 受信データの取り扱いを修正
2022-10-27 Androidのビルド設定を修正
2022-10-27 PIP(ピクチャーインピクチャー)用のパッチを追加
2022-10-27 AndroidManifest.xmlを修正
2022-10-27 lastDateの取り扱いを修正
2022-10-27 警告の条件を修正
2022-10-29 パッチ場所をわかりやすく修正
2022-10-30 XML保存に失敗していたのを修正
2022-11-08 Projectの作り直し
2022-12-08 誤検知防止用処理追加
2022-12-08 ・使用していない機能を削除 ・MPU6050の情報取得部分を実装
2023-02-11 MPU6050から取得した値をシリアルに出力するように修正
2023-02-12 angleをgyroに修正
2023-02-12 出力を修正
2023-03-05 未テスト
2023-03-05 Serial通信で取得したデータを取得できるように修正
2023-03-06 試行錯誤中
2023-03-20 コミット
2023-06-02 いろいろ修正
2023-06-11 データの受信方法を修正中
2023-06-11 不要なコードの削除
2023-11-04 基板修正
    [MultiMeter-B_Cu.gbr, MultiMeter-B_Mask.gbr, MultiMeter-B_Paste.gbr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]
2023-11-04 起動時にボイス追加(案) メーターのスピードを1割増し表示(UIなし)
    [VoiceList.xlsx]
2023-11-04 UI修正
2023-11-04 スポーツモード追加 音声追加
2023-11-04 回路図修正
    [MultiMeter.kicad_pcb, MultiMeter.kicad_sch]
2023-11-16 外部モニター用のArduinoを作成中
